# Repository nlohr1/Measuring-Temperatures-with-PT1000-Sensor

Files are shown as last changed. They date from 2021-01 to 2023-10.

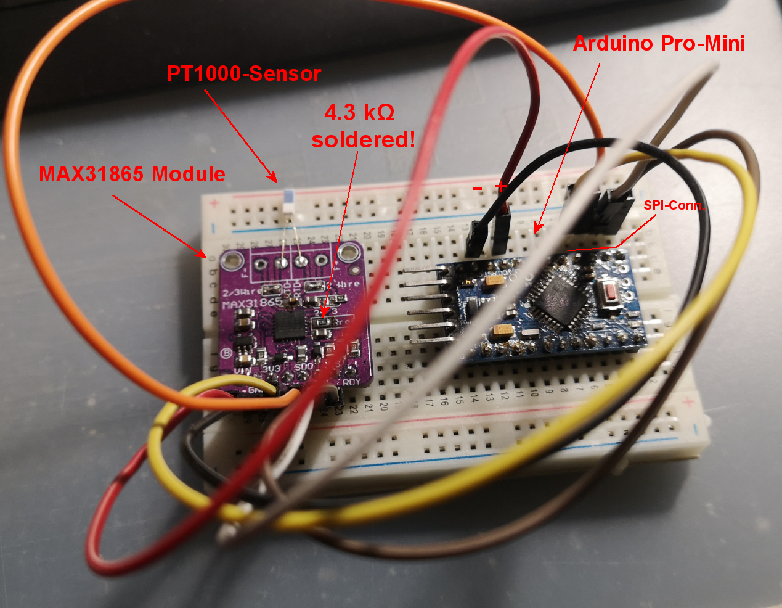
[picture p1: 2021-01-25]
MAX31865_with_Breadboard_Foto.png

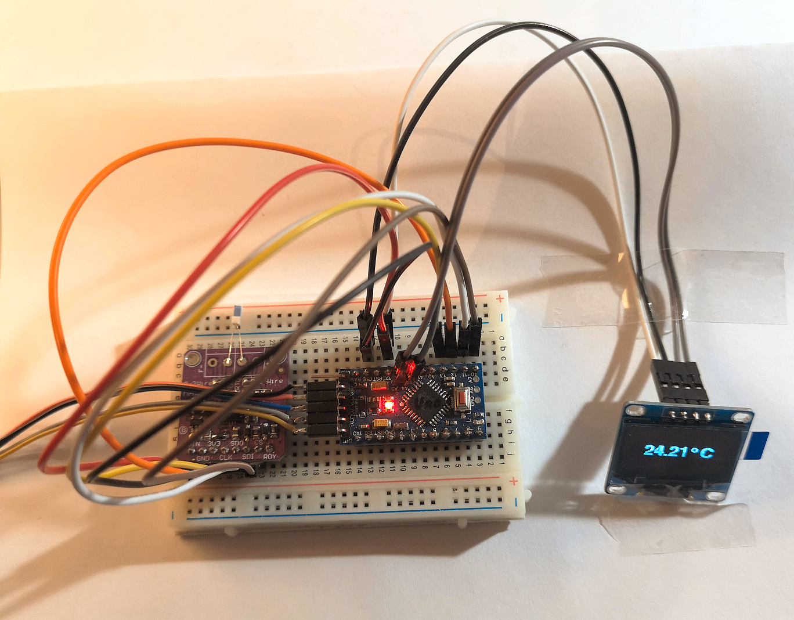
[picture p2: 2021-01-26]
MAX31865_with_Breadboard_&_OLED_Foto.png

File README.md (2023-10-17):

# Measuring Temperatures with PT1000-Sensor v1.1
High accurate Temperature-measures (down to ±0.1°C) with Adafruits MAX31865 Module and a *small* PT1000-Sensor,
using an ATMega328(Arduino) and an OLED-Module (connected via I2C) to view Reults in °C.

Schematic
Case

A description + instructions of the MAX31865 Module from Adafruit can be read on their site:
https://learn.adafruit.com/adafruit-max31865-rtd-pt100-amplifier/

I used a *small* PT1000-Sensor from Delta-R (=> https://delta-r.de/de/elemente/pt/pt-1.000/pt-1000-2b/38/2x2-pt1000-2b-7500c),
due to the fact that a PT1000 has more voltage amplitude (to measure) as a PT100, so precision of reading per default is more precise
and has fewer noise and resistances (on cables). A small Sensor like this also is much faster reaching the objects temperature
to measure (fewer time-loss waiting for "ready").
But preciseness of reading the real temp. also depends on how we connect the Sensor physically to the measured Object.
I use a small bit of Thermal Paste between the PT1000-Sensor and the measuring-object (Att.: Sensor connected before heating the object ;-).

The translation of the small read voltage isn't analogue as used often in old boards with PTCs (PositiveTemperatureCoefficient Sensor)
obtaining bad results because of "noise", added resistances and offset-voltages from cables, etc. as described above.
So through SPI-Connection (4 cables + GND/V+) and short connections there are not so many possible measuring faults.
The Arduino-Code from Adafruit is really simple, (see file "Adafruit_MAX31865_PT100-P1000-RTD-Sensor.ino"), using the Adafruit-Library:
https://github.com/adafruit/Adafruit_MAX31865 (download).

Converting the Readings (measured values) for the small I2C-OLED-Output (128x64px):
I choosed Temperature in °C to be the value from interest. For good readability I used a bigger and (IMHO) nicer font as the
default fonts provided from Adafruit-GFX-library.
Downloaded "FreeSansBold.ttf", modified with the (free) App "FontForge" using therein only the essential necessary letters: number
44 to 67 from ASCII-Table) to minify RAM-consumption in the ATMega328.
I compiled this resulted .ttf-font with "fontconvert.exe" to a usable Bitmap-font, named "FreeSnBld12pt7b.h" to use for the OLED.
If you like it, feel free to use it without restrictions besides the licensing of the original font ("FreeSansBold.ttf"), which is
(IMHO) a nicer Sans-Serif font on a small OLED as used.

## Measuring alternative with analog Amplifier
For anyone who prefers a more traditional method, amplifying measured voltages with an Analog-Amplifier in combination with (my) preferred
PT1000-Sensor-Type, the alternative (for shorter wires) is to use a Differentiation Amplifier, so also this method may cancel Offset-Voltages
and Noises. I used an ADS1115 SMD-IC as amplifier in combination with a TL431-LDO (SMD-IC), which provides the stabilized 1,000V reference-voltage
through a following Current/Voltage OpAmp (LMV321) network to one of the two Input-Pins of the ADS1115-Amplifier, therefore providing this
high-stablizized voltage as 1,000 milliAmpere to the PT-1000 Sensor, beeing capable to output highly reliable (reference-)values - with the
same principle as above through I²C-wires to the Arduino.

With two identical PT1000-Sensors (and translating-methods as described), both attached together it is relatively clear that errors are minimized reliably - *if* both
Sensors also are coupled together with Thermal paste inside a heated-pipe (⇒ as "thermocouple"-pipe, turned with the lathe from a 1/4"-Cu-Pipe
as soldering-tip-attachment "micro-oven") – and if both values finally are displaying nearly the same or similar values on the temperature-coordinate.
Attached a schematic to turn on the lathe with a 1/4"-Cu-pipe (min. 50mm length, to obtain a 35mm-pipe).

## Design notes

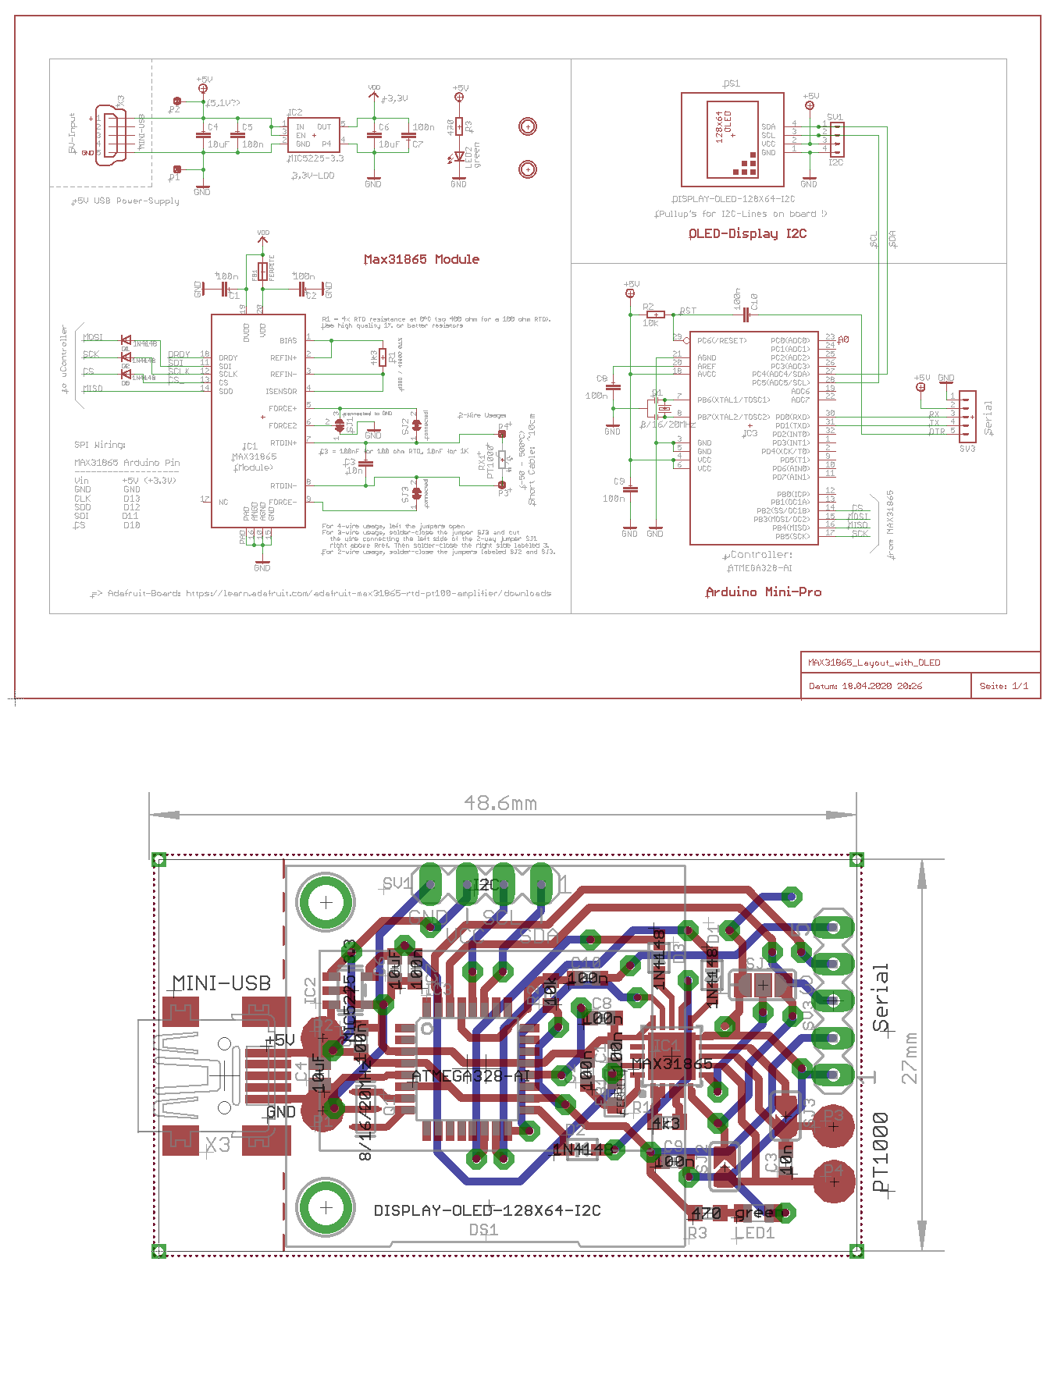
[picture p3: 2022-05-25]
MAX31865_Layout_with_OLED.png

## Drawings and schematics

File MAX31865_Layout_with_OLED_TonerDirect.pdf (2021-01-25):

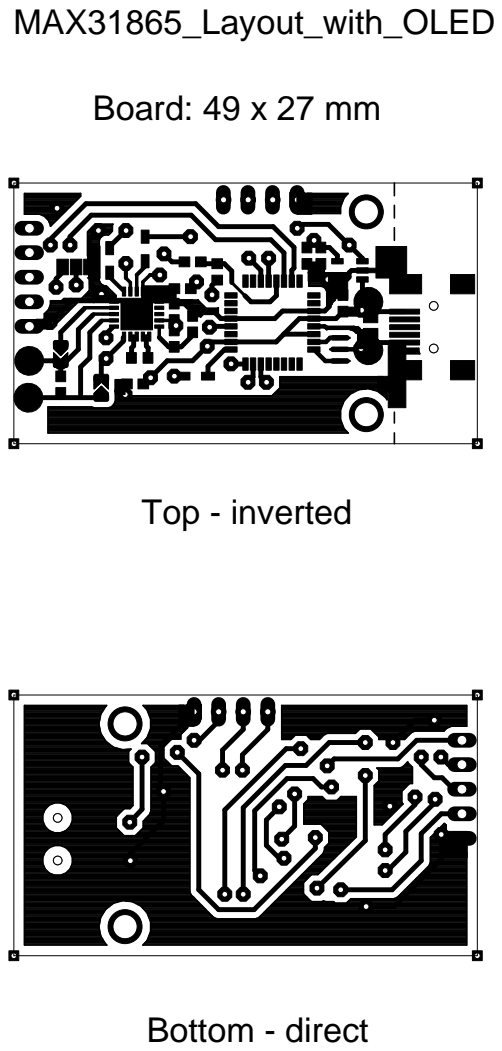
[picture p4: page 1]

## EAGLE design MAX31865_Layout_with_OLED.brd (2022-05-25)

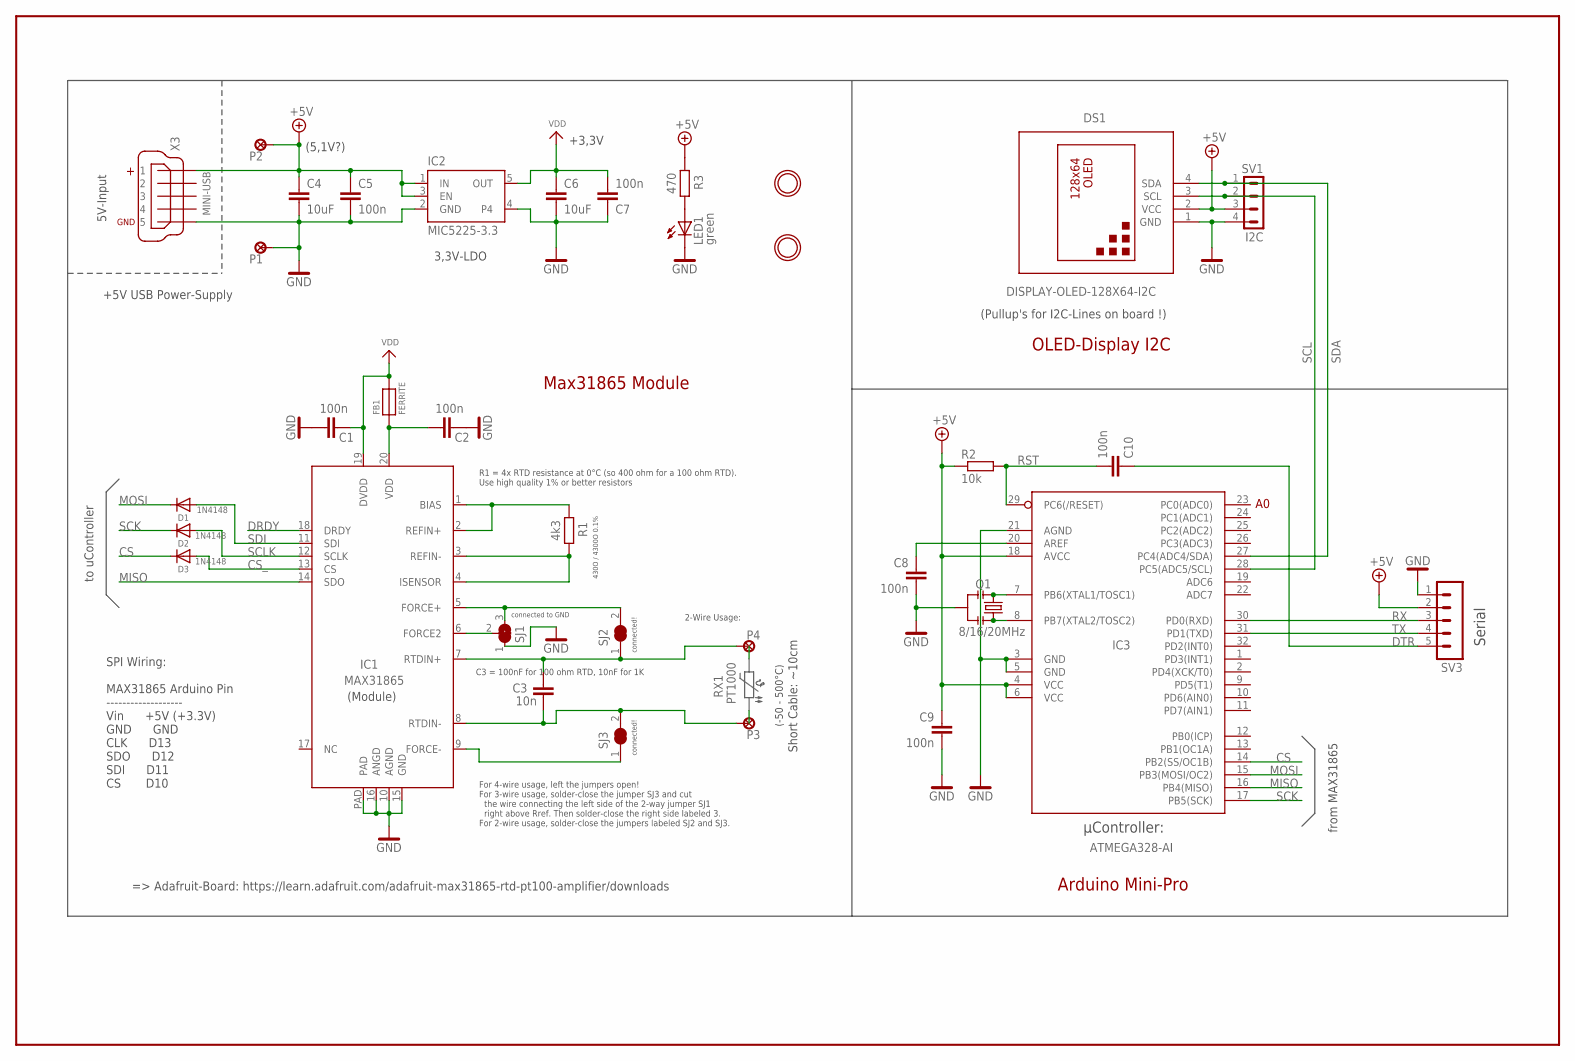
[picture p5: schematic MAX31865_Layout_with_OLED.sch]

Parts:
C1, C2, C5, C7, C8, C9, C10: 100n; C0603
C3: 10n; C0603
C4: 10uF; C0805
C6: 10uF; C0603
D1, D2, D3: 1N4148; SOD-323
DS1: DISPLAY-OLED-128X64-I2C
FB1: FERRITE; 0603
IC1: MAX31865; QFN20_4MM_0.65MM
IC2: MIC5225-3.3; SOT23-5
IC3: ATMEGA328-AI; TQFP32-08
LED1: green; CHIPLED_0805
P1, P2, P3, P4: LSP15
Q1: 8/16/20MHz; RESONATOR-SMD-1:1
R1: 4k3; R0603
R2: 10k; R0603
R3: 470; R0603
SJ1: SOLDERJUMPER_2WAY; SOLDERJUMPER_2WAY_OPEN_NOPASTE
SJ2, SJ3: SOLDERJUMPER; SOLDERJUMPER_ARROW_NOPASTE
SV1: I2C; MA04-1
SV3: MA05-1
U$2, U$19: MOUNTINGHOLE2.5; MOUNTINGHOLE_2.5_PLATED
X3: MINI-USB; 32005-201

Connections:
+5V: C4.1, C5.1, C9.1, DS1.2 (VCC), IC2.1 (IN), IC2.3 (EN), IC3.4 (VCC), IC3.6 (VCC), IC3.18 (AVCC), P2.P$1, R2.1, R3.1, SV1.3, SV3.2, X3.1
AREF: C8.1, IC3.20 (AREF)
CS: D3.C, IC3.14 (PB2(SS/OC1B))
CS_: D3.A, IC1.13 (CS)
DRDY: IC1.18 (DRDY)
DTR: C10.1, SV3.5
FORCE2: IC1.6 (FORCE2), SJ1.2
FORCE+: IC1.5 (FORCE+), SJ1.3, SJ2.2
FORCE-: IC1.9 (FORCE-), SJ3.1
GND: C1.2, C2.1, C4.2, C5.2, C6.2, C7.1, C8.2, C9.2, DS1.1 (GND), IC1.10 (AGND), IC1.15 (GND), IC1.16 (ANGD), IC1.PAD, IC2.2 (GND), IC2.4, IC3.3 (GND), IC3.5 (GND), IC3.21 (AGND), LED1.C, P1.P$1, Q1.2, SJ1.1, SV1.4, SV3.1, X3.5
MISO: IC1.14 (SDO), IC3.16 (PB4(MISO))
MOSI: D1.C, IC3.15 (PB3(MOSI/OC2))
unnamed: C2.2, FB1.1, IC1.20 (VDD)
unnamed: IC1.1 (BIAS), IC1.2 (REFIN+), R1.1
unnamed: IC1.3 (REFIN-), IC1.4 (ISENSOR), R1.2
unnamed: IC3.7 (PB6(XTAL1/TOSC1)), Q1.1
unnamed: IC3.8 (PB7(XTAL2/TOSC2)), Q1.3
unnamed: LED1.A, R3.2
RST: C10.2, IC3.29 (PC6(/RESET)), R2.2
RTDIN+: C3.1, IC1.7 (RTDIN+), P4.P$1, SJ2.1
RTDIN-: C3.2, IC1.8 (RTDIN-), P3.P$1, SJ3.2
RX: IC3.30 (PD0(RXD)), SV3.3
SCK: D2.C, IC3.17 (PB5(SCK))
SCL: DS1.3 (SCL), IC3.28 (PC5(ADC5/SCL)), SV1.2
SCLK: D2.A, IC1.12 (SCLK)
SDA: DS1.4 (SDA), IC3.27 (PC4(ADC4/SDA)), SV1.1
SDI: D1.A, IC1.11 (SDI)
TX: IC3.31 (PD1(TXD)), SV3.4
VDD: C1.1, C6.1, C7.2, FB1.2, IC1.19 (DVDD), IC2.5 (OUT)

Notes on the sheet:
µController:
(-50 - 500°C)
Short Cable: ~10cm
C3 = 100nF for 100 ohm RTD, 10nF for 1K
R1 = 4x RTD resistance at 0°C (so 400 ohm for a 100 ohm RTD). Use high quality 1% or better resistors
(5,1V?)
5V-Input
Serial
(Module)
connected!
to uController
=> Adafruit-Board: https://learn.adafruit.com/adafruit-max31865-rtd-pt100-amplifier/downloads
+5V USB Power-Supply
3,3V-LDO
+3,3V
connected to GND
For 4-wire usage, left the jumpers open! For 3-wire usage, solder-close the jumper SJ3 and cut the wire connecting the left side of the 2-way jumper SJ1 right above Rref. Then solder-close the right side labeled 3. For 2-wire usage, solder-close the jumpers labeled SJ2 and SJ3.
2-Wire Usage:
(Pullup's for I2C-Lines on board !)
430O / 4300O 0.1%
SPI Wiring: MAX31865 Arduino Pin ------------------- Vin +5V (+3.3V) GND GND CLK D13 SDO D12 SDI D11 CS D10
Max31865 Module
Arduino Mini-Pro
OLED-Display I2C
from MAX31865

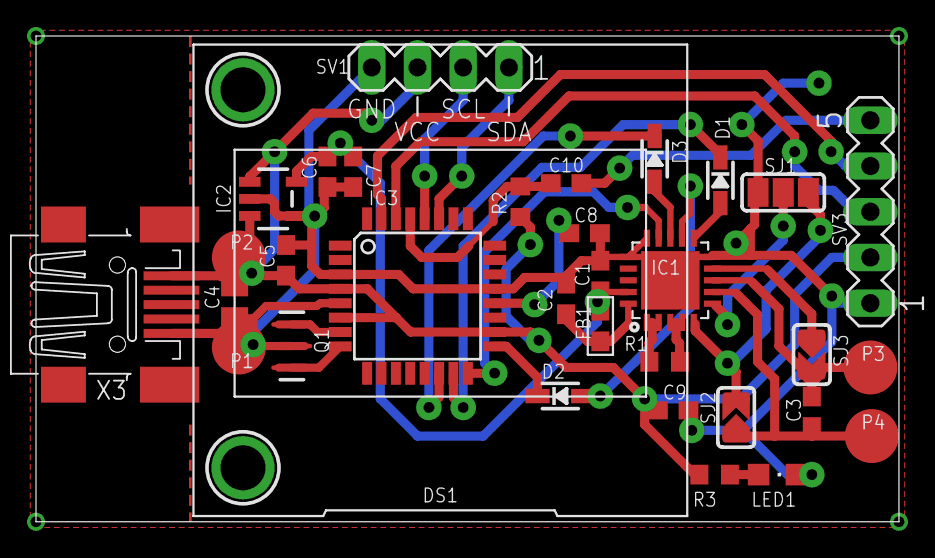
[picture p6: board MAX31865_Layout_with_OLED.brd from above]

Board: 2 copper layers, 47.9 x 27.0 mm, 35 parts (0 on the bottom side), 28 nets.

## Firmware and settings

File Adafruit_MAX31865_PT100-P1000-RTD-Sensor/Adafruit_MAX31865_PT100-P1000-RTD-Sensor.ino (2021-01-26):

/*************************************************** 
  This is a library for the Adafruit PT100/P1000 RTD Sensor w/MAX31865

  Designed specifically to work with the Adafruit RTD Sensor
  ----> https://www.adafruit.com/products/3328

  This sensor uses SPI to communicate, 4 pins are required to  
  interface
  Adafruit invests time and resources providing this open source code, 
  please support Adafruit and open-source hardware by purchasing 
  products from Adafruit!

  Written by Limor Fried/Ladyada for Adafruit Industries.  
  BSD license, all text above must be included in any redistribution
 ****************************************************/
#include <Adafruit_MAX31865.h>

#include <Wire.h>               //I2C communication library to communicate with OLED-Display

//+LCD-library:
#include <Adafruit_GFX.h>       //Graphics library
#include <Adafruit_SSD1306.h>   //OLED display library
#include <Fonts/FreeSnBld12pt7b.h> //Include a (selfmade) bigger display-font (12x7pt=17x12px) to display the temperature - see instruction @ the end!

#define OLED_RESET 9            //(free) Reset pin # (or -1 if sharing Arduino reset pin)
Adafruit_SSD1306 display(128, 64, &Wire, OLED_RESET); //Set OLED display to the present real size

//Prepare the MAX31865 Module:
// Use software SPI: CS, DI, DO, CLK
Adafruit_MAX31865 thermo = Adafruit_MAX31865(10, 11, 12, 13);
// use hardware SPI, just pass in the CS pin
//Adafruit_MAX31865 thermo = Adafruit_MAX31865(10);

// The value of the Rref resistor. Use 430.0 for PT100 and 4300.0 for PT1000
#define RREF      4300.0  //nl: calibrate this value using a precise Mutltimeter!
// The 'nominal' 0-degrees-C resistance of the sensor
// 100.0 for PT100, 1000.0 for PT1000
#define RNOMINAL  1000.0

void setup() {
  Serial.begin(115200);
  Serial.println("Adafruit MAX31865 PT100 Sensor Test!");

  thermo.begin(MAX31865_2WIRE);  // set to 2WIRE or 4WIRE as necessary //nl: using *short* wires, sowe need only 2-wires !

  // !!!!!!!!!!!!!!!!!!!!!!!!!!!!!! Set the I2C-Adress for the display !!!!!!!!!!!!!!!!!!!!!!!!!!!!!!!!!!!!!!!!!!!!!!!
  // by default, the high voltage is generated from the 3.3V line internally
  display.begin (SSD1306_SWITCHCAPVCC, 0x3C); //initialize with the I2C addr 0x3C or 0x3D (Adafruit-default = 0x3D)
  // !!!!!!!!!!!!!!!!!!!!!!!!!!!!!!!!!!!!!!!!!!!!!!!!!!!!!!!!!!!!!!!!!!!!!!!!!!!!!!!!!!!!!!!!!!!!!!!!!!!!!!!!!!!!!!!!!
  display.setTextSize(1);   //Set default font size to the smallest available (default)
  display.setTextColor(WHITE); //Set font to display white color on black background
  display.invertDisplay(0); //Set display to normal video (white fonts and drawings over black background, "1" is viceversa)
  display.setFont(&FreeSnBld12pt7b); //display values with a bigger and fewer RAM consumed font (= modified freefont)
}


void loop() {
  uint16_t rtd = thermo.readRTD();
//============ Prining collecteddata on a Serial-Output ============
Serial.print("RTD value: "); Serial.println(rtd); // Resistance value of the RTD (here PT1000)
//  float ratio = rtd;
//  ratio /= 32768;

//  Serial.print("Ratio = "); Serial.println(ratio,8);
//  Serial.print("Resistance = "); Serial.println(RREF*ratio,8);
  Serial.print("Temperature = "); Serial.println(thermo.temperature(RNOMINAL, RREF));

  // Check and print any faults on a Serial-Line:
  uint8_t fault = thermo.readFault();
  if (fault) {
    Serial.print("Fault 0x"); Serial.println(fault, HEX);
    if (fault & MAX31865_FAULT_HIGHTHRESH) {
      Serial.println("RTD High Threshold"); 
    }
    if (fault & MAX31865_FAULT_LOWTHRESH) {
      Serial.println("RTD Low Threshold"); 
    }
    if (fault & MAX31865_FAULT_REFINLOW) {
      Serial.println("REFIN- > 0.85 x Bias"); 
    }
    if (fault & MAX31865_FAULT_REFINHIGH) {
      Serial.println("REFIN- < 0.85 x Bias - FORCE- open"); 
    }
    if (fault & MAX31865_FAULT_RTDINLOW) {
      Serial.println("RTDIN- < 0.85 x Bias - FORCE- open"); 
    }
    if (fault & MAX31865_FAULT_OVUV) {
      Serial.println("Under/Over voltage"); 
    }
    thermo.clearFault();
  }
  Serial.println();
//============ End of Serial-Output ============

//************** Display the Temperature on the OLED-Display in gC: **************
  display.clearDisplay(); //Clear display buffer from last cycle to begin drawing new display-values:
  //display.print("RTD value: "); display.println(rtd); //print the read RTD value 
  display.setCursor(20, 40); //Position cursor...
  int i = thermo.temperature(RNOMINAL, RREF); //transform float to int
  if (i < 100) {display.print("  ");} //align the temp. at right-side
  if (i < 1000) {display.print(" ");}
  //display.println(rtd); //nl: not need to display Resistance-value of the RTD (PT1000) here
  display.print(thermo.temperature(RNOMINAL, RREF)); //display the Temperature in gC
  ////display.drawCircle(100,32,1,WHITE); //Draw a degree symbol after temperature
  display.print(";C"); //Display "gC" (modified ttf-library: ';' => 'small circle', "fontconvert.exe FreeSansBold.ttf 12 44 67 > FreeSnBld12pt7b.h" (see aloso Adafruit_GFX_Library)
  //display.print(" C");
  display.display(); //write values in buffer onto the Display
// *********** End OLED-Display ***********
  
  delay(1000);
}

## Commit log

2021-01-25 Add files via upload
    With the Adafruits "MAX31865" Module it is possible to measure temperatures with high accuracy (within ±0.1°C), from -40°C up to 750°C, here converted to a readable format with a DIY-Arduino-Board an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
    I use it to control the measures from NTC3950 measured f.ex. on 3D-Printers extruders, heaters (oven), etc.
    [MAX31865_Layout_with_OLED.brd, MAX31865_Layout_with_OLED.sch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]
2021-01-26 Add files via upload
    Now apart of Serial-Monitor added the OLED-Display, showing additional Wiring (Foto) and adding code to the (original Adafruit) Program-Sketch.

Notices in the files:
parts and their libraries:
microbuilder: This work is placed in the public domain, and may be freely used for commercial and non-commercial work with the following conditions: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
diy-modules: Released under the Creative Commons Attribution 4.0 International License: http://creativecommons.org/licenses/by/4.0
